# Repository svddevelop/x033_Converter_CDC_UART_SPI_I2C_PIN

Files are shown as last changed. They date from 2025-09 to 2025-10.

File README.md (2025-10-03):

# USB programmable converter based on CH32X033

Using CDC (USB) connection you can

programmatically control interfaces

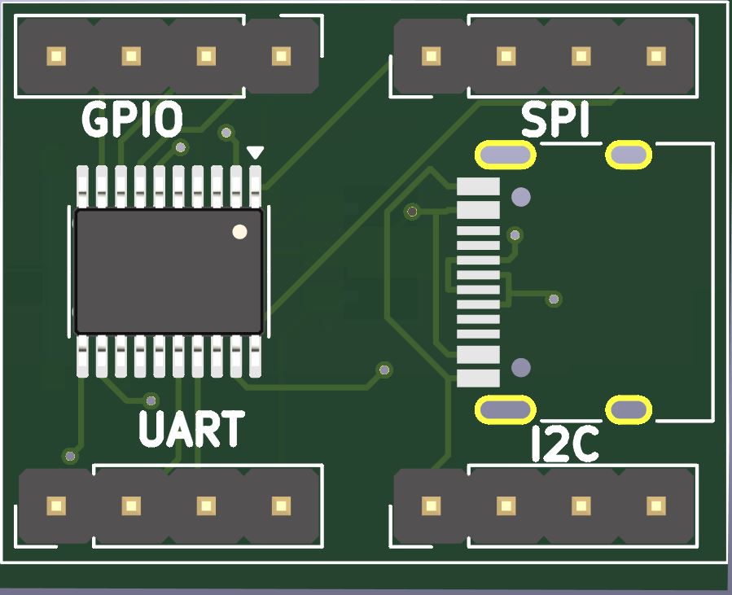
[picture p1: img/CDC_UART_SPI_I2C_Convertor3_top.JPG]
<img src="img/cfg-CDC_UART_SPI_I2C_Convertor3_top.JPG" width="100"
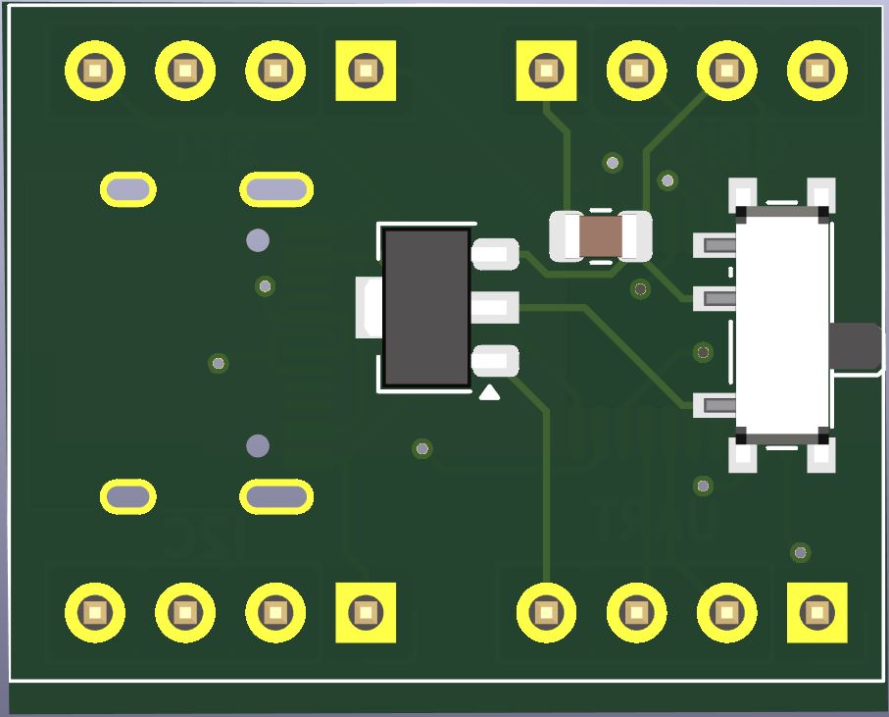
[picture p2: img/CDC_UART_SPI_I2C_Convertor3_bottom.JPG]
<img src="img/cfg-CDC_UART_SPI_I2C_Convertor3_bottom.JPG" width="100">
		

## Current commands
When the device is connected via USB, by connecting a terminal, you can get help on using the control commands. At the end of each command there must be a CR (0x0D) symbol.

### [help]
outputs information about possible commands.

### [print]
outputs the current configuration settings

### [helpuart]
commands for configuring the UART interface:

### [helpspi]
shows list of commands for configuring the SPI interface:

### [helpi2c]
shows list of commands for configuring the UART interface:

### [SAVE]

saves the current setting to the flash. On the next powrt connection of the device, this configuration will be automatic activated.

#### [SET:UART.DIS]
makes the UART interface unused.

##### [SET:UART.DIS]
activates the UART interface.

#### [SET:UART.BAUD=\<int value>]
Sets the communication speed for the UART interface. <int value> must be a value from 1200 to 2500000 baud per second.

Example: [SET:UART.BAUD=57600] - sets the communication speed to 57600.

### [SET:SPI.PRESC=\<char value>]
set the base clock prescaler:

BASE CLOCK = 48MHz /(2 << PRESC );

### [SET:SPI.BAUD=\<char value>]
makes division of base clock (see PRESC) with value:

  0	divede by 2,  
  1	divide by 4,  
  2	divide by 8,  
  3	divide by 16,  
  4	divide by 32,  
  5	divide by 54,  
  6	divide by 128,  
  7	divide by 256.  

#### [SET:SPI.DIS]
makes the SPI interface unused.

#### [SET:SPI.DIS]
activates the SPI interface.

#### [SET:SPI.CPOL=\<char val>]
set up the clock polarity (0 or 1); 

#### [SET:SPI.CPHA=\<char val>]
set up the clock phase (0 or 1); 

#### [TRN:\<dev src>-\<dev dst>.EN/DIS]
allow or disallow to transwer between interfaces where <dev src> and <dev dst> is:

  CDC, UART, SPI or I2C;
		
for example:

  [TRN:CDS-UART.EN] - allow a trafik from CDS to UART.
	
  [TRN:UART-UART.EN] - allow a trafik from UART to CDS.

---

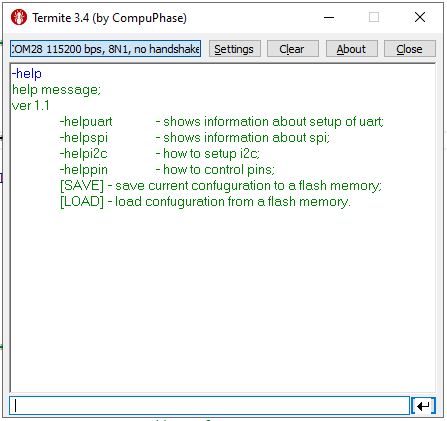
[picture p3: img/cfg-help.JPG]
<img src="img/cfg-help.JPG" width="100">
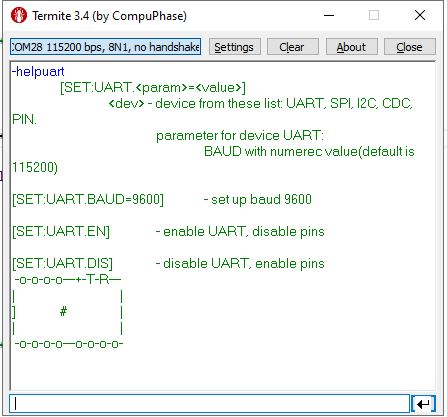
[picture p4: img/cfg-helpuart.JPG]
<img src="img/cfg-helpuart.JPG" width="100">
 
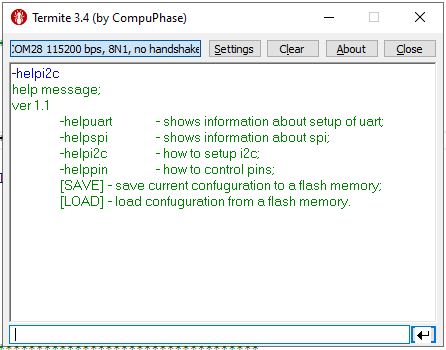
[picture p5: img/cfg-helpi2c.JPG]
<img src="img/cfg-helpi2c.JPG" width="100">

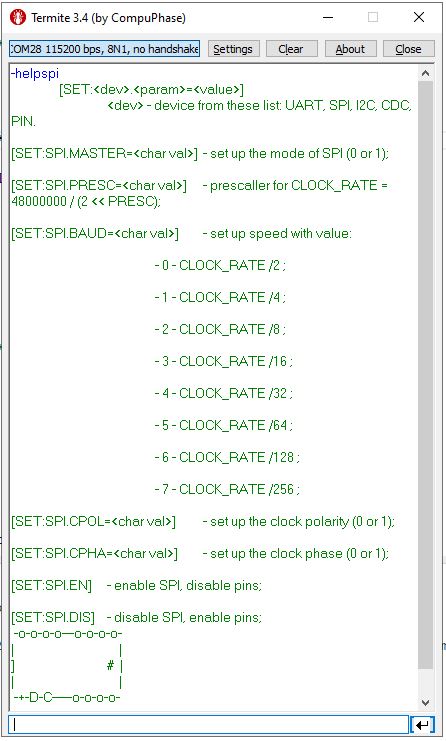
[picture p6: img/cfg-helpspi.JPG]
<img src="img/cfg-helpspi.JPG" width="100">
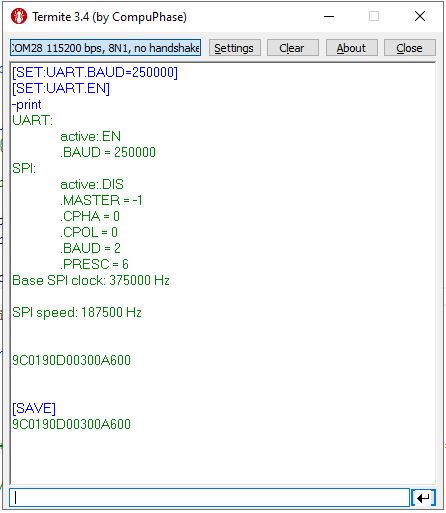
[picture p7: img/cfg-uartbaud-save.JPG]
<img src="img/cfg-uartbaud-save.JPG" width="100">


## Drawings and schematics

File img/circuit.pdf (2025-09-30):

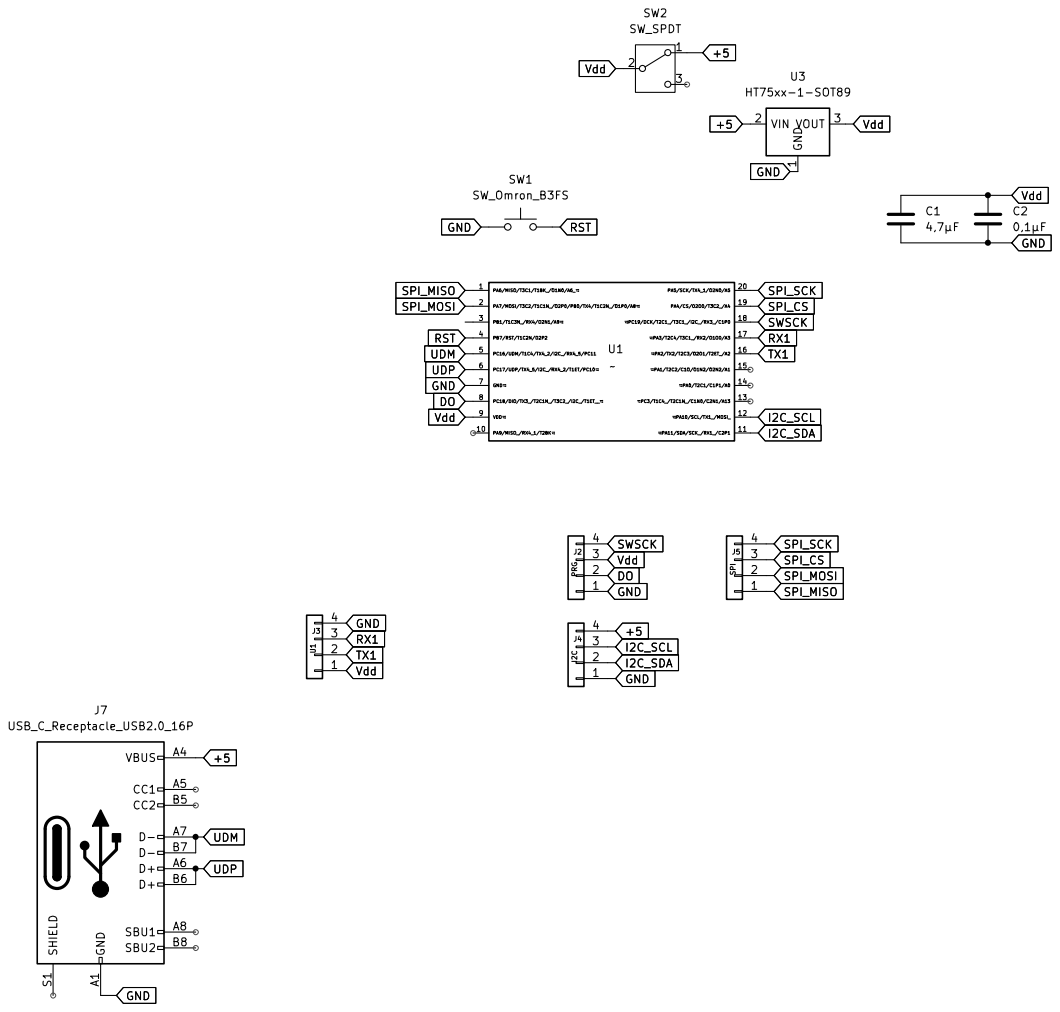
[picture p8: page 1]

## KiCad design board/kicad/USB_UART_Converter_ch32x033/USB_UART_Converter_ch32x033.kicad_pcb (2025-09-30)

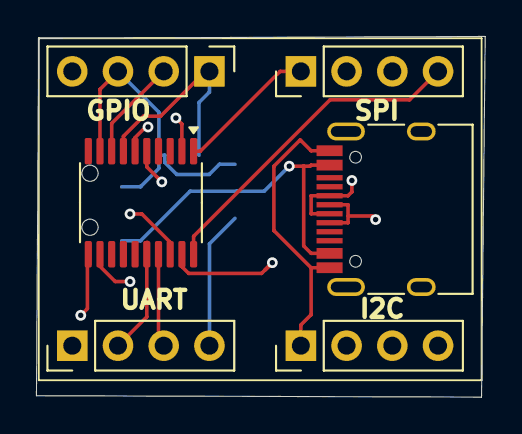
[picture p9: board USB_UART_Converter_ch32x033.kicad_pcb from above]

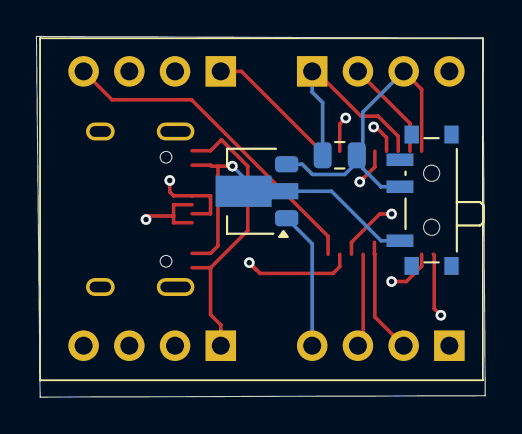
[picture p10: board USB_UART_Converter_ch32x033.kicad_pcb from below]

Board: 4 copper layers, 24.9 x 20.0 mm, 9 parts (3 on the bottom side), 15 nets.

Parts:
C1: 4,7µF; C_0805_2012Metric
J2: PRG; PinHeader_1x04_P2.54mm_Vertical
J3: U1; PinHeader_1x04_P2.54mm_Vertical
J4: I2C; PinHeader_1x04_P2.54mm_Vertical
J5: SPI; PinHeader_1x04_P2.54mm_Vertical
J7: USB_C_Receptacle_USB2.0_16P; USB_C_Receptacle_HRO_TYPE-C-31-M-12
SW2: SW_SPDT; SW_SPDT_PCM12
U1: TSSOP-20_4.4x6.5mm_P0.65mm
U3: HT75xx-1-SOT89; SOT-89-3

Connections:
+5: J4.4, J7.A4 (VBUS), J7.A9 (VBUS), J7.B4 (VBUS), J7.B9 (VBUS), SW2.1 (A), U3.2 (VIN)
DO: J2.2, U1.8 (PC18/DIO/TX3_/T2C1N_/T3C2_/I2C_/T1ET__)
GND: C1.2, J2.1, J3.4, J4.1, J7.A1 (GND), J7.A12 (GND), J7.B1 (GND), J7.B12 (GND), U1.7 (GND), U3.1 (GND)
I2C_SCL: J4.3, U1.12 (PA10/SCL/TX1_/MOSI_)
I2C_SDA: J4.2, U1.11 (PA11/SDA/SCK_/RX1_/C2P1)
RX1: J3.3, U1.17 (PA3/T2C4/T3C1_/RX2/O1O0/A3)
SPI_CS: J5.3, U1.19 (PA4/CS/O2O0/T3C2_/A4)
SPI_MISO: J5.1, U1.1 (PA6/MISO/T3C1/T1BK_/O1N0/A6_)
SPI_MOSI: J5.2, U1.2 (PA7/MOSI/T3C2/T1C1N_/O2P0/PB0/TX4/T1C2N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)
SPI_SCK: J5.4, U1.20 (PA5/SCK/TX4_1/O2N0/A5)
SWSCK: J2.4, U1.18 (PC19/DCK/T2C1_/T3C1_/I2C_/RX3_/C1P0)
TX1: J3.2, U1.16 (PA2/TX2/T2C3/O2O1/T2ET_/A2)
UDM: J7.A7 (D-), J7.B7 (D-), U1.5 (PC16/UDM/T1C4/TX4_2/I2C_/RX4_5/PC11)
UDP: J7.A6 (D+), J7.B6 (D+), U1.6 (PC17/UDP/TX4_5/I2C_/RX4_2/T1ET/PC10)
Vdd: C1.1, J2.3, J3.1, SW2.2 (B), U1.9 (VDD), U3.3 (VOUT)

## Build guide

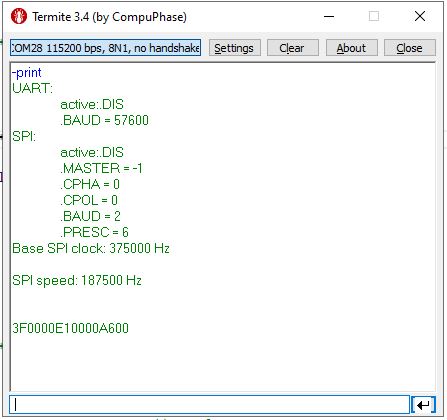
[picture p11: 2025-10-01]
img/cfg-print.JPG

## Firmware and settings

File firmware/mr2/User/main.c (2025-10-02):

// ===================================================================================
// Project:   Example for CH32X035/X034/X033
// Version:   v1.0
// Year:      2023
// Author:    Sergej Pfaffenrot, based on Stefan Wagner's code
// Github:    https://
// EasyEDA:   https://
// License:   http://creativecommons.org/licenses/by-sa/3.0/
// ===================================================================================
//
// Description:
// ------------
// Blink example.
//
// References:
// -----------
// - WCH Nanjing Qinheng Microelectronics: http://wch.cn
//
// Compilation Instructions:
// -------------------------
// - Make sure GCC toolchain (gcc-riscv64-unknown-elf, newlib) and Python3 with
//   chprog and rvprog (via pip) are installed. In addition, Linux requires access
//   rights to the USB bootloader.
// - Press the BOOT button on the MCU board and keep it pressed while connecting it
//   via USB to your PC.
// - Run 'make flash'.


// ===================================================================================
// Libraries, Definitions and Macros
// ===================================================================================

/*              PIN CONNECTION x033F8P6
 *
 * {7}          GND
 * {9}          Vdd
 *
 * {5} PC16/11  UDM
 * {6} PC17/10  UDP
 *
 * {8} PC18     SWDIO
 * {18}PC19     SWSCK
 *
 * {16}PA2      TX2
 * {17}PA3      RX2
 *
 * {2}PB0       TX4
 * {3}PB1       RX4
 *
 *
 *
 */



#include "system.h"                               // system functions
#include "gpio/gpio.h"                                 // GPIO functions
#include "USB/usb_cdc.h"
#include "uart/uart.h"

#include "flash/flash_userdata.h"
#include "sys/print.h"
#include <stdlib.h>
#include "flash/dev_config.h"
#include "cmd/cdc_cmd.h"


#define PIN_LED PB1                               // define LED pin

static char cdc_buffer[256];
static uint16_t cdc_buffer_len = 0;

#ifndef __code
#define __code const __attribute__((section(".rodata")))
#endif

configuration_t global_conf;


// ===================================================================================
// Main Function
// ===================================================================================
int main(void) {

    CLK_init();
    HSI_enable();
 



  // Setup
  //PIN_output(PIN_LED);                            // set LED pin to output
  
  CDC_init();

  //**************************************************************

    cfg_init(&global_conf);
    configuration_t loc ;

    read_struct_from_flash((char*)&loc, sizeof(configuration_t));
    
    uint8_t crc = calc_cfg_crc(&loc);

    if ( crc != loc.crc)
        cfg_init(&loc);
    else 
        global_conf = loc;

    activate_cfg(&global_conf);

  //**************************************************************

  // Loop
  while(1) {
    //PIN_toggle(PIN_LED);                          // toggle LED
    //DLY_ms(1);                                      // wait a bit

    int count = CDC_available();
    if (count ){

        if ( count > sizeof(cdc_buffer))
            count = sizeof(cdc_buffer);


        for (int i = 0; i < count; i++){
            cdc_buffer[i] = CDC_read();

        }
        cdc_buffer_len = count;

        if ( ifcmdexec(cdc_buffer, &global_conf ) ){

            count = 0;
            for(int i = 0; i < sizeof(cdc_buffer); i++ )
                cdc_buffer[i] = 0;

        }


        if ( count > 0 ){

            /*for (int i = 0; i < count; i++){


                char ch = cdc_buffer[i];
                UART2_write( ch );
                //CDC_write( ch ); // for test of buffer

                //UART4_write( ch );
            }*/

            process_cdc( &global_conf, cdc_buffer, &cdc_buffer_len );

        }
        CDC_flush();

    }

    process_uart( &global_conf );


    /*
    if ( UART2_available() ){

        CDC_write( UART2_read() );
        CDC_flush();
    }
    */
    /*
    if ( UART4_available() ){

        CDC_write( UART4_read() );
        CDC_flush();
    }
    */

  }
}

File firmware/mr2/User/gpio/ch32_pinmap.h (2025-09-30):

#ifndef __CH32_PINMAP_H
#define __CH32_PINMAP_H

// ===========================================================
//   ????????????? ????? ????? ??? CH32 (V003, X035, V203)
// ===========================================================
//
// ?????:
//   - #define ADC_CHANNEL_PAx   <????? ??????>   (???? ???? ADC)
//   - #define PWM_PIN_PAx       TIMx,ch          (???? ???????????? PWM)
//   - #define HAS_ADC_PAx       1 / 0
//   - #define HAS_PWM_PAx       1 / 0
//
// ?????????????: analogRead(PAx), analogWrite(PBx, val)
// ===========================================================


// ===========================================================
// CH32V003 (?????????, ?? 20 ???)
// ===========================================================
#if defined(CH32V003)

// --- ADC ---
#define ADC_CHANNEL_PA1   1
#define ADC_CHANNEL_PA2   2
#define ADC_CHANNEL_PA3   3
#define ADC_CHANNEL_PA4   4
#define ADC_CHANNEL_PA5   5
#define ADC_CHANNEL_PA6   6
#define ADC_CHANNEL_PA7   7

#define HAS_ADC_PA1 1
#define HAS_ADC_PA2 1
#define HAS_ADC_PA3 1
#define HAS_ADC_PA4 1
#define HAS_ADC_PA5 1
#define HAS_ADC_PA6 1
#define HAS_ADC_PA7 1

// --- PWM (TIM1) ---
#define PWM_PIN_PA2  TIM1,1
#define PWM_PIN_PA3  TIM1,2
#define PWM_PIN_PA4  TIM1,3
#define PWM_PIN_PA7  TIM1,4

#define HAS_PWM_PA2 1
#define HAS_PWM_PA3 1
#define HAS_PWM_PA4 1
#define HAS_PWM_PA7 1


// ===========================================================
// CH32X035 (???????, ?? 48 ???, ?????? STM32F030/F051)
// ===========================================================
#elif defined(CH32X035)

// --- ADC ---
#define ADC_CHANNEL_PA0   0
#define ADC_CHANNEL_PA1   1
#define ADC_CHANNEL_PA2   2
#define ADC_CHANNEL_PA3   3
#define ADC_CHANNEL_PA4   4
#define ADC_CHANNEL_PA5   5
#define ADC_CHANNEL_PA6   6
#define ADC_CHANNEL_PA7   7
#define ADC_CHANNEL_PB0   8
#define ADC_CHANNEL_PB1   9

#define HAS_ADC_PA0 1
#define HAS_ADC_PA1 1
#define HAS_ADC_PA2 1
#define HAS_ADC_PA3 1
#define HAS_ADC_PA4 1
#define HAS_ADC_PA5 1
#define HAS_ADC_PA6 1
#define HAS_ADC_PA7 1
#define HAS_ADC_PB0 1
#define HAS_ADC_PB1 1

// --- PWM (TIM1, TIM3, TIM14/15/16) ---
#define PWM_PIN_PA8  TIM1,1
#define PWM_PIN_PA9  TIM1,2
#define PWM_PIN_PA10 TIM1,3
#define PWM_PIN_PA11 TIM1,4

#define PWM_PIN_PA6  TIM3,1
#define PWM_PIN_PA7  TIM3,2
#define PWM_PIN_PB0  TIM3,3
#define PWM_PIN_PB1  TIM3,4

#define PWM_PIN_PA4  TIM14,1
#define PWM_PIN_PA2  TIM15,1
#define PWM_PIN_PA3  TIM15,2
#define PWM_PIN_PA6  TIM16,1

#define HAS_PWM_PA8  1
#define HAS_PWM_PA9  1
#define HAS_PWM_PA10 1
#define HAS_PWM_PA11 1
#define HAS_PWM_PA6  1
#define HAS_PWM_PA7  1
#define HAS_PWM_PB0  1
#define HAS_PWM_PB1  1
#define HAS_PWM_PA4  1
#define HAS_PWM_PA2  1
#define HAS_PWM_PA3  1


// ===========================================================
// CH32V203 (STM32F103-???????????, ?? 64 ???)
// ===========================================================
#elif defined(CH32V203)

// --- ADC ---
#define ADC_CHANNEL_PA0   0
#define ADC_CHANNEL_PA1   1
#define ADC_CHANNEL_PA2   2
#define ADC_CHANNEL_PA3   3
#define ADC_CHANNEL_PA4   4
#define ADC_CHANNEL_PA5   5
#define ADC_CHANNEL_PA6   6
#define ADC_CHANNEL_PA7   7
#define ADC_CHANNEL_PB0   8
#define ADC_CHANNEL_PB1   9
#define ADC_CHANNEL_PC0  10
#define ADC_CHANNEL_PC1  11
#define ADC_CHANNEL_PC2  12
#define ADC_CHANNEL_PC3  13
#define ADC_CHANNEL_PC4  14
#define ADC_CHANNEL_PC5  15

#define HAS_ADC_PA0 1
#define HAS_ADC_PA1 1
#define HAS_ADC_PA2 1
#define HAS_ADC_PA3 1
#define HAS_ADC_PA4 1
#define HAS_ADC_PA5 1
#define HAS_ADC_PA6 1
#define HAS_ADC_PA7 1
#define HAS_ADC_PB0 1
#define HAS_ADC_PB1 1
#define HAS_ADC_PC0 1
#define HAS_ADC_PC1 1
#define HAS_ADC_PC2 1
#define HAS_ADC_PC3 1
#define HAS_ADC_PC4 1
#define HAS_ADC_PC5 1

// --- PWM (TIM2, TIM3, TIM4) ---
#define PWM_PIN_PA0  TIM2,1
#define PWM_PIN_PA1  TIM2,2
#define PWM_PIN_PA2  TIM2,3
#define PWM_PIN_PA3  TIM2,4

#define PWM_PIN_PA6  TIM3,1
#define PWM_PIN_PA7  TIM3,2
#define PWM_PIN_PB0  TIM3,3
#define PWM_PIN_PB1  TIM3,4

#define PWM_PIN_PB6  TIM4,1
#define PWM_PIN_PB7  TIM4,2
#define PWM_PIN_PB8  TIM4,3
#define PWM_PIN_PB9  TIM4,4

#define HAS_PWM_PA0 1
#define HAS_PWM_PA1 1
#define HAS_PWM_PA2 1
#define HAS_PWM_PA3 1
#define HAS_PWM_PA6 1
#define HAS_PWM_PA7 1
#define HAS_PWM_PB0 1
#define HAS_PWM_PB1 1
#define HAS_PWM_PB6 1
#define HAS_PWM_PB7 1
#define HAS_PWM_PB8 1
#define HAS_PWM_PB9 1

#endif // family selector

#endif // __CH32_PINMAP_H

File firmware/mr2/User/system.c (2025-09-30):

// ===================================================================================
// Basic System Functions for CH32X035/X034/X033                              * v1.2 *
// ===================================================================================
//
// This file must be included!!!!
//
// References:
// -----------
// - WCH Nanjing Qinheng Microelectronics: http://wch.cn
//
// 2023 by Stefan Wagner:   https://github.com/wagiminator

#include "system.h"

// ===================================================================================
// Setup Microcontroller (this function is called automatically at startup)
// ===================================================================================
void SYS_init(void) {

  // Init system clock
  #if SYS_CLK_INIT > 0
    #if F_CPU <= 12000000
      //FLASH->ACTLR = FLASH_ACTLR_LATENCY_0;
    #elif F_CPU <= 24000000
      FLASH->ACTLR = FLASH_ACTLR_LATENCY_1;
    #else
      FLASH->ACTLR = FLASH_ACTLR_LATENCY_2;
    #endif
    RCC->CFGR0 = SYS_CLK_DIV;
  #endif

  // Init SYSTICK
  #if SYS_TICK_INIT > 0
    STK_init();
  #endif

  // Enable GPIO
  #if SYS_GPIO_EN > 0
    RCC->APB2PCENR = RCC_IOPAEN | RCC_IOPBEN | RCC_IOPCEN;
  #endif
}

// ===================================================================================
// System Clock Functions
// ===================================================================================

// Reset system clock to default state
void CLK_reset(void) {
  RCC->CTLR   |= (uint32_t)0x00000001;
  RCC->CFGR0   = (uint32_t)0x00000050;
  FLASH->ACTLR = (uint32_t)0x00000000;
}

// Setup pin PB9 for MCO (output, push-pull, alternate)
void MCO_init(void) {
  RCC->APB2PCENR |= RCC_AFIOEN | RCC_IOPBEN;
  GPIOB->CFGHR    = (GPIOB->CFGHR & ~((uint32_t)0b1111<<(1<<2))) | ((uint32_t)0b1011<<(1<<2));
  RCC->CFGR0     |= RCC_CFGR0_MCO_SYSCLK;
}

// ===================================================================================
// Delay Functions
// ===================================================================================

// Wait n counts of SysTick
void DLY_ticks(uint32_t n) {
  uint32_t end = STK->CNTL + n;
  while(((int32_t)(STK->CNTL - end)) < 0);
}

// ===================================================================================
// Bootloader (BOOT) Functions
// ===================================================================================

// Perform software reset and jump to bootloader
void BOOT_now(void) {
  FLASH->KEYR = FLASH_KEY1;
  FLASH->KEYR = FLASH_KEY2;
  FLASH->BOOT_MODEKEYR = FLASH_KEY1;
  FLASH->BOOT_MODEKEYR = FLASH_KEY2;      // unlock flash
  FLASH->STATR = FLASH_STATR_BOOT_MODE;   // start bootloader after software reset
  FLASH->CTLR  = FLASH_CTLR_LOCK;         // lock flash
  RCC->RSTSCKR = RCC_RMVF;                // clear reset flags
  PFIC->SCTLR  = PFIC_SYSRESET;           // perform software reset
}

// ===================================================================================
// Independent Watchdog Timer (IWDG) Functions
// ===================================================================================

// Start independent watchdog timer (IWDG) with given amount of WDG clock cycles
// (ticks). The IWDG clock is HSI/1024/prescaler. One tick is 64*1024*1000/48000000 ms
// long, max ticks is 4095 = 5591ms.
// Once the IWDG has been started, it cannot be disabled, only reloaded (feed).
void IWDG_start_t(uint16_t ticks) {
  IWDG->CTLR = 0x5555;                    // allow register modification
  while(IWDG->STATR & IWDG_PVU);          // wait for clock register to be ready
  IWDG->PSCR = 0b100;                     // set clock prescaler 64
  while(IWDG->STATR & IWDG_RVU);          // wait for reload register to be ready
  IWDG->RLDR = ticks;                     // set watchdog counter reload value
  IWDG->CTLR = 0xAAAA;                    // load reload value into watchdog counter
  IWDG->CTLR = 0xCCCC;                    // enable IWDG
}

// Reload watchdog counter with n ticks, n<=4095
void IWDG_reload_t(uint16_t ticks) {
  IWDG->CTLR = 0x5555;                    // allow register modification
  while(IWDG->STATR & IWDG_RVU);          // wait for reload register to be ready
  IWDG->RLDR = ticks;                     // set watchdog counter reload value
  IWDG->CTLR = 0xAAAA;                    // load reload value into watchdog counter
}

// ===================================================================================
// Automatic Wake-up Timer (AWU) Functions
// ===================================================================================

// Init and start automatic wake-up timer
void AWU_init(void) {
  AWU->CSR = 0x02;                        // enable automatic wake-up timer
  EXTI->EVENR |= ((uint32_t)1<<27);       // enable AWU event
  EXTI->RTENR |= ((uint32_t)1<<27);       // enable AWU rising edge triggering
}

// Stop automatic wake-up timer
void AWU_stop(void) {
  AWU->CSR = 0x00;                        // disable automatic wake-up timer
  EXTI->EVENR &= ~((uint32_t)1<<27);      // disable AWU event
  EXTI->RTENR &= ~((uint32_t)1<<27);      // disable AWU rising edge triggering
}

// ===================================================================================
// Sleep Functions
// ===================================================================================

// Put device into sleep, wake up by interrupt
void SLEEP_WFI_now(void) {
  PFIC->SCTLR &= ~PFIC_SLEEPDEEP;         // set power-down mode to SLEEP
  __WFI();                                // wait for interrupt
}

// Put device into sleep, wake up by event
void SLEEP_WFE_now(void) {
  PFIC->SCTLR &= ~PFIC_SLEEPDEEP;         // set power-down mode to SLEEP
  __WFE();                                // wait for event
}

// Put device into stop, wake up interrupt
void STOP_WFI_now(void) {
  PFIC->SCTLR |= PFIC_SLEEPDEEP;          // set power-down mode to STOP
  __WFI();                                // wait for interrupt
}

// Put device into stop, wake up event
void STOP_WFE_now(void) {
  PFIC->SCTLR |= PFIC_SLEEPDEEP;          // set power-down mode to STOP
  __WFE();                                // wait for event
}

// Put device into standby (deep sleep), wake up interrupt
void STDBY_WFI_now(void) {
  RCC->APB1PCENR |= RCC_PWREN;            // enable power module
  PWR->CTLR      |= PWR_CTLR_PDDS;        // set power-down mode to STANDBY
  PFIC->SCTLR    |= PFIC_SLEEPDEEP;
  __WFI();                                // wait for interrupt
  PWR->CTLR      &= ~PWR_CTLR_PDDS;       // reset power-down mode
}

// Put device into standby (deep sleep), wake up event
void STDBY_WFE_now(void) {
  RCC->APB1PCENR |= RCC_PWREN;            // enable power module
  PWR->CTLR      |= PWR_CTLR_PDDS;        // set power-down mode to STANDBY
  PFIC->SCTLR    |= PFIC_SLEEPDEEP;
  __WFE();                                // wait for event
  PWR->CTLR      &= ~PWR_CTLR_PDDS;       // reset power-down mode
}
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

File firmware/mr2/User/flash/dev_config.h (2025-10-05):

#pragma once

#ifdef __cplusplus
extern "C" {
#endif

/* pins 
 //uart
 PA2
 PA3

 //spi
 PA4
 PA5
 PA6
 PA7

 //i2c
 PA10
 PA11

 //gpio
 PC18
 PC19 //wo
 */ 

#define PIN_UART_RX         1
#define PIN_UART_TX         0

#define PIN_SPI_CS          2
#define PIN_SPI_SCK         3
#define PIN_SPI_MISO        4
#define PIN_SPI_MOSI        5

#define PIN_I2C_SCL         6
#define PIN_I2C_SDA         7

#define PIN_PIN_1           8
#define PIN_PIN_2           9


#define IS_PIN_UART(x)     ((x == 0)||(x == 1))
#define IS_PIN_SPI(x)      ((x == 2)||(x == 3)||(x == 4)||(x == 5))
#define IS_PIN_I2C(x)      ((x == 6)||(x == 7))
#define IS_PIN_PC19(x)      (x == 9)

 #define PINMODE_INP        0
 #define PINMODE_INPPD      1
 #define PINMODE_INPPU      2
 #define PINMODE_INPAN      3
 #define PINMODE_OUT        4     

#define SET_PIN_MODE(pin, mode) \
    ((mode) == 0 ? PIN_input(pin) : \
    ((mode) == 1 ? PIN_input_PD(pin) : \
    ((mode) == 2 ? PIN_input_PU(pin) : \
    ((mode) == 3 ? PIN_input_AN(pin) : \
     (mode) == 4 ? PIN_output(pin) : (void)0))))

#define GET_PIN_BY_INDEX(x) \
    ((x) == PIN_UART_TX ? PA2 : \
     (x) == PIN_UART_RX ? PA3 : \
     (x) == PIN_SPI_CS ? PA4 : \
     (x) == PIN_SPI_SCK ? PA5 : \
     (x) == PIN_SPI_MISO ? PA6 : \
     (x) == PIN_SPI_MOSI ? PA7 : \
     (x) == PIN_I2C_SCL ? PA10 : \
     (x) == PIN_I2C_SDA ? PA11 : \
     (x) == PIN_PIN_1 ? PC18 : \
     (x) == PIN_PIN_2 ? PC19 : 0)     

#include <stdint.h>
#include <stdbool.h>

typedef struct __attribute__((__packed__)){

    char uart:1;
    char spi:1;
    char i2c:1;

} cfg_active_intefaces_t;

typedef struct __attribute__((__packed__)){
    
    uint32_t baud;

} cfg_uart_t;

typedef struct __attribute__((__packed__)){

    uint8_t prescaller:4;
    uint8_t baud:3;
    char master: 1;
    char hw_cs: 1;
    char pha: 1;
    char pol: 1;

} cfg_spi_t;

typedef struct __attribute__((__packed__)){

    uint8_t cdc_uart:1;
    uint8_t uart_cdc:1;

    uint8_t cdc_spi:1;
    uint8_t spi_cdc:1;

    uint8_t cdc_i2c:1;
    uint8_t i2c_cdc:1;

    uint8_t spi_uart:1;
    uint8_t uart_spi:1;

    uint8_t i2c_uart:1;
    uint8_t uart_i2c:1;

    uint8_t spi_i2c:1;
    uint8_t i2c_spi:1;


} transfer_t;

typedef struct __attribute__((__packed__)){
    char mode: 4;
    //char interrupt: 4;

} cfg_pin_t;

typedef struct __attribute__((__packed__)){

        cfg_pin_t pa2;
        cfg_pin_t pa3;

        //spi
        cfg_pin_t pa4;
        cfg_pin_t pa5;
        cfg_pin_t pa6;
        cfg_pin_t pa7;

        //i2c
        cfg_pin_t pa10;
        cfg_pin_t pa11;

        //gpio
        cfg_pin_t pc18;
        cfg_pin_t pc19; //wo

} cfg_pins_t;


typedef struct __attribute__((__packed__,aligned(4))){

    uint8_t crc;
    cfg_active_intefaces_t active_interfaces;
    cfg_uart_t cfg_uart;
    cfg_spi_t cfg_spi;

    transfer_t trans;
    cfg_pins_t cfg_pins;

} configuration_t;


#define CFG_CRC_SIZE    (sizeof(configuration_t)-1)

#define CONF_FILL_CRC(x)    x.crc = 
void        onfiguration_init(configuration_t * a_inst);
bool        is_conf_valid(configuration_t * a_inst);
configuration_t conf_read_from_flash();
bool        conf_write_to_flash(configuration_t* a_conf);

void        cfg_uart_init(cfg_uart_t* a_conf);
void        cfg_spi_init(cfg_spi_t* a_conf);
void        cfg_pins_init(cfg_pins_t *a_conf);
void        cfg_init(configuration_t * a_conf);
void        activate_cfg(configuration_t * a_conf);
uint8_t     calc_cfg_crc(configuration_t * a_conf);

extern configuration_t global_conf;

#ifdef __cplusplus
}
#endif

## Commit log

2025-09-30 README, img
    [USB_UART_Converter_ch32x033.kicad_pcb, USB_UART_Converter_ch32x033.kicad_sch]
2025-09-30 SPI integration; cdc_cmd - help, spi params;
2025-10-01 fix for set uart.baud
    [dev_config.c]
2025-10-02 UART with IRQ works fine
2025-10-04 part with spi interface
